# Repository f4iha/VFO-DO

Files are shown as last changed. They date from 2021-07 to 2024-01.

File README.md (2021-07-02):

# VFO-DO RF Generator

This VFO-DO is a HF generator covering from few kHz to 100MHz. This project provide to any beginner in electronic or radio the necessary elements to build a source of stable frequency (precise at the Herz level due to the steering by a GPS)... and it is very simple to build.

It is coming from the initial idea from Gene Marcus W3PM/GM4YRE and published in an [article](http://www.arrl.org/files/file/QEX_Next_Issue/2015/Jul-Aug_2015/Marcus.pdf) of QEX.
This repository is an evolution of the work done by F6ITU who provided a [KiCad project](https://github.com/F6ITU/VFO-DO/) for this VFO-DO.

This project can be used as field equipements, where it is unthinkable to move a served oscillator (fragile and expensive). This is mainly a simple approach to drive a little SDR or replace the VFO of a traditional radio device.

The cost of this is around 30 euros. However, please take in account the phase noise of this type of generator cannot compete with a traditional VFO-DO

## Specific features

During the integration, few changes were applied in the initial code of the author:
  * usage of a I2C Crystal Display, it is freeing multiple pin on the Arduino
  * add a button to disable the GPS at start

## Intellectual property and licence

The intellectual property and the publishing rights are owned respectively by the author and the publishing society mentioned.

Permission is granted to use, copy, modify, and distribute this firmware and documentation for non-commercial purposes.

## External links

More informations on the oscillator module based on SiLabs Si5351 : 
[https://learn.adafruit.com/adafruit-si5351-clock-generator-breakout?view=all](https://learn.adafruit.com/adafruit-si5351-clock-generator-breakout?view=all)

Another source for this module 
[https://www.sv1afn.com/si5351a.html](https://www.sv1afn.com/si5351a.html)
Careful : this last module is not "pin compatible" with the previous one

Origin firmware from the author [http://www.knology.net/~gmarcus/Si5351/Si5351_vfo_v5.ino.zip](http://www.knology.net/~gmarcus/Si5351/Si5351_vfo_v5.ino.zip)

A WSPR emitter-receiver designed by the author and using the VFO-DO
[http://www.knology.net/~gmarcus/Si5351/Si5351A_WSPR_XCVR.pdf](http://www.knology.net/~gmarcus/Si5351/Si5351A_WSPR_XCVR.pdf)

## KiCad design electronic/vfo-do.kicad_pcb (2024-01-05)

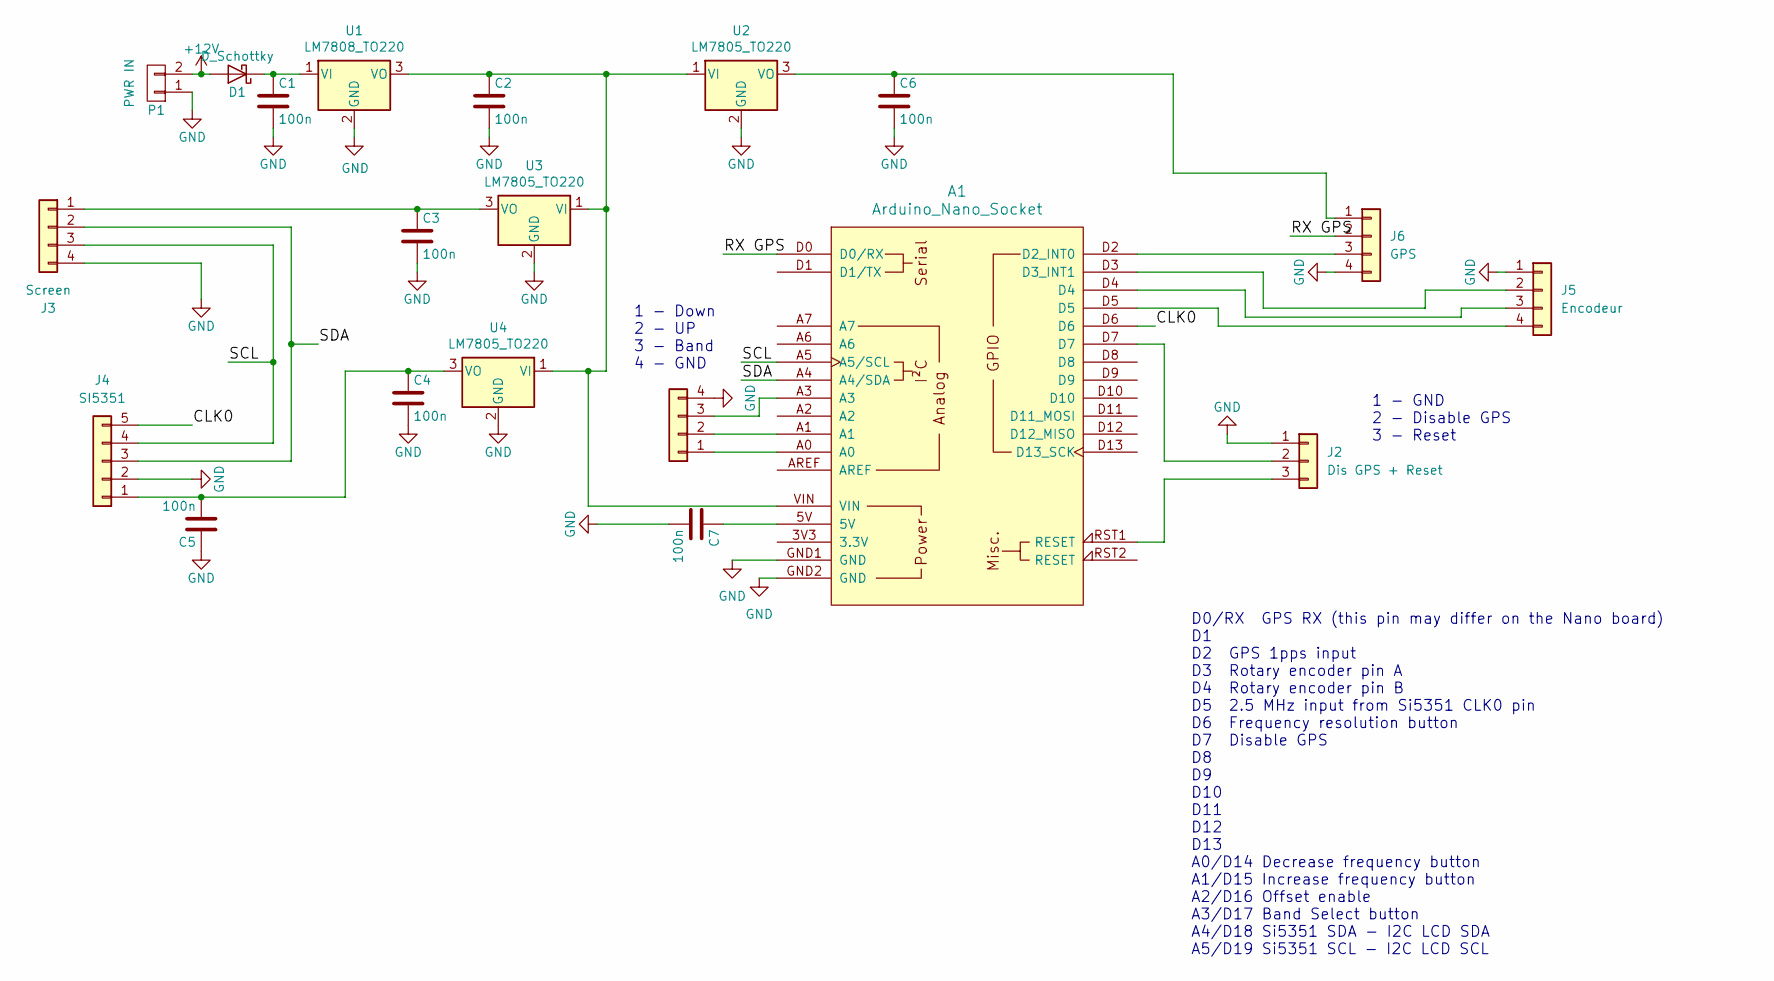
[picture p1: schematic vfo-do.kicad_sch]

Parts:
A1: Arduino_Nano_Socket
C1, C2, C3, C4, C5, C6, C7: 100n; C_Disc_D5.0mm_W2.5mm_P5.00mm
D1: D_Schottky; D_DO-41_SOD81_P7.62mm_Horizontal
J1: Commands; Molex_KK-254_AE-6410-04A_1x04_P2.54mm_Vertical
J2: Dis GPS + Reset; Molex_KK-254_AE-6410-03A_1x03_P2.54mm_Vertical
J3: Screen; Molex_KK-254_AE-6410-04A_1x04_P2.54mm_Vertical
J4: SI5351; Molex_KK-254_AE-6410-05A_1x05_P2.54mm_Vertical
J5: Encodeur; Molex_KK-254_AE-6410-04A_1x04_P2.54mm_Vertical
J6: GPS; Molex_KK-254_AE-6410-04A_1x04_P2.54mm_Vertical
P1: PWR IN; Molex_KK-254_AE-6410-02A_1x02_P2.54mm_Vertical
U1: LM7808_TO220; TO-220-3_Vertical
U2, U3, U4: LM7805_TO220; TO-220-3_Vertical

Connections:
+12V: D1.2 (A), P1.2
/CLK0: A1.D6, J4.5
/RX GPS: A1.D0 (D0/RX), J6.2
/SCL: A1.A5 (A5/SCL), J3.3, J4.4
/SDA: A1.A4 (A4/SDA), J3.2, J4.3
GND: A1.GND1 (GND), A1.GND2 (GND), C1.2, C2.2, C3.2, C4.2, C5.1, C6.2, C7.2, J1.4, J2.1, J3.4, J4.2, J5.1, J6.4, P1.1, U1.2 (GND), U2.2 (GND), U3.2 (GND), U4.2 (GND)
unnamed: A1.D2 (D2_INT0), J6.3
unnamed: A1.D3 (D3_INT1), J5.2
unnamed: A1.5V, C7.1
unnamed: C1.1, D1.1 (K), U1.1 (VI)
unnamed: A1.A0, J1.1
unnamed: A1.A1, J1.2
unnamed: A1.A3, J1.3
unnamed: A1.D7, J2.2
unnamed: A1.RST1 (RESET), J2.3
unnamed: C3.1, J3.1, U3.3 (VO)
unnamed: C4.1, C5.2, J4.1, U4.3 (VO)
unnamed: A1.D4, J5.3
unnamed: A1.D5, J5.4
unnamed: C6.1, J6.1, U2.3 (VO)
unnamed: A1.VIN, C2.1, U1.3 (VO), U2.1 (VI), U3.1 (VI), U4.1 (VI)

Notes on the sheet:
1 - Down 2 - UP 3 - Band 4 - GND
D0/RX GPS RX (this pin may differ on the Nano board) D1 D2 GPS 1pps input D3 Rotary encoder pin A D4 Rotary encoder pin B D5 2.5 MHz input from Si5351 CLK0 pin D6 Frequency resolution button D7 Disable GPS D8 D9 D10 D11 D12 D13 A0/D14 Decrease frequency button A1/D15 Increase frequency button A2/D1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
1 - GND 2 - Disable GPS 3 - Reset

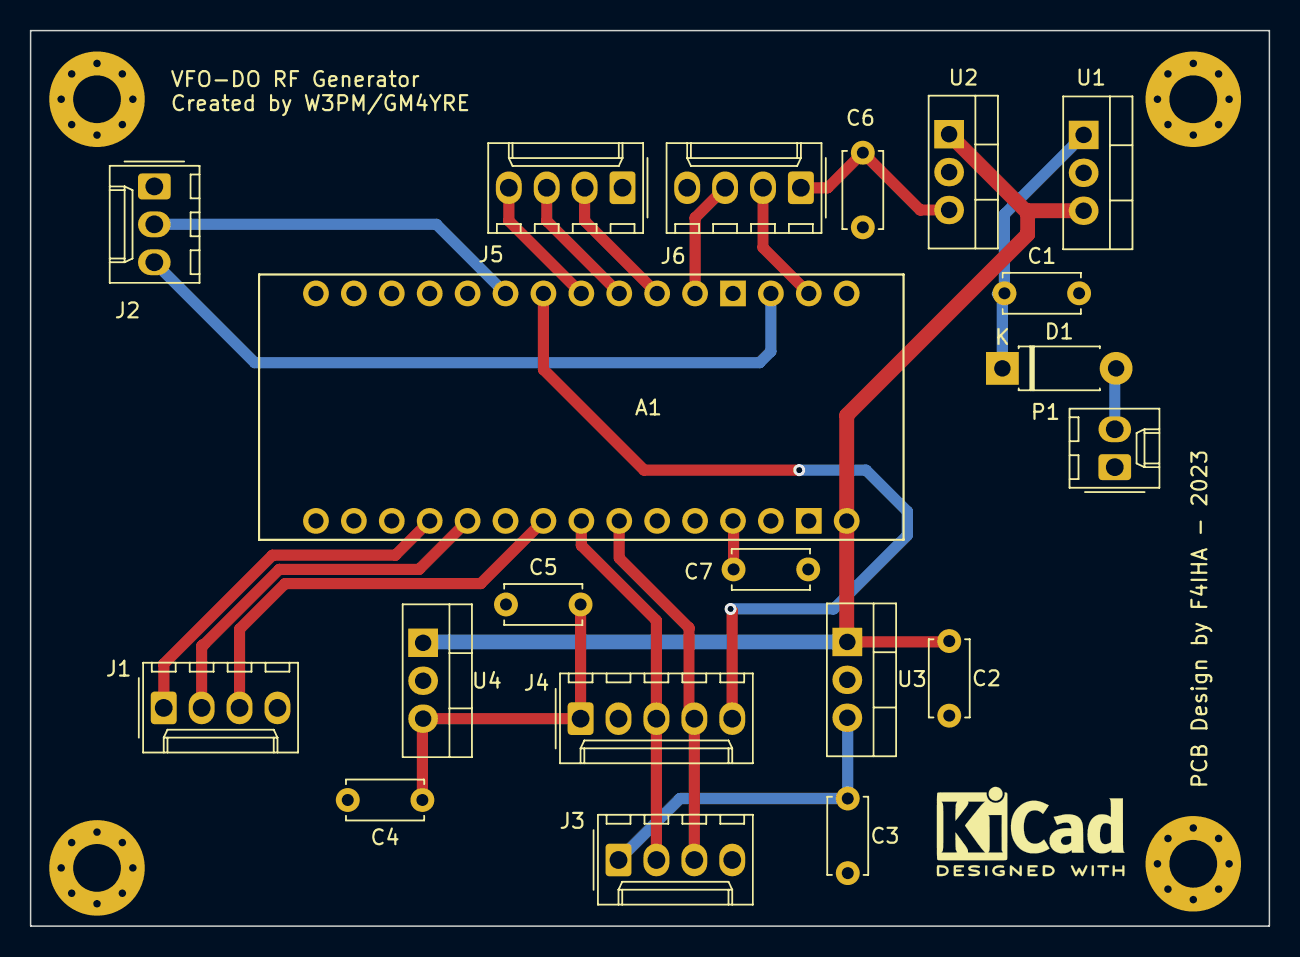
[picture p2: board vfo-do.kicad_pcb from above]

Board: 2 copper layers, 83.0 x 60.0 mm, 20 parts (0 on the bottom side), 21 nets.

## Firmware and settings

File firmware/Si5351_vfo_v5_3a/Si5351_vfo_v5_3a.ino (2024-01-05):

/*

 Arduino Controlled GPS Corrected Dual Output Si5351A VFO
 
 A VFO project that uses an Arduino Uno or Nano to control a SI5351A clock 
 generator breakout board. The VFO may be used in stand-alone mode or with 
 a GPS receiver to software calibrate the output frequency.
 
 Permission is granted to use, copy, modify, and distribute this software
 and documentation for non-commercial purposes.
 
 Copyright (C) 2014,  Gene Marcus W3PM GM4YRE
 
 16 December,2014
 
 v5     12 July, 2015    Corrected band select algorithm
 v5_1   13 July, 2015    Changed "KHz" to "kHZ" in the LCD frequency display
 v5_2   20 September,    2016 Modified debounce function to be compatible with 
                         Arduino IDE 1.6.11
 v5_3   28 January,2017  Modified coding to enhance 9600 operation. The modifcation
                         is courtesy of Jan, PE1CID.
 v5_3a  11 March, 2021   The variable "validGPSflag" can now equal 1 or 2 to proceed 
                         with normal operation                        
     
                                        
 
 Acknowledgements: 

 Special thanks to Jan, PE1CID for his effort to streamline the code and improve 
 operation at 9600 baud. Portions of the GPS receive code were influenced by 
 Igor Gonzalez Martin's Arduino tutorial. Thanks to N2END for finding compatibility 
 bug with Arduino 1.6.11 and testing revision v5_2.
 
 
 ------------------------------------------------------------------------
 Nano Digital Pin Allocation
 
 D0/RX  GPS RX (this pin may differ on the Nano board)
 D1  
 D2  GPS 1pps input 
 D3  Rotary encoder pin A
 D4  Rotary encoder pin B
 D5  Frequency resolution button
 D6  2.5 MHz input from Si5351 CLK0 pin
 D7  Disable GPS
 D8  
 D9  
 D10 
 D11
 D12
 D13 
 A0/D14 Decrease frequency button
 A1/D15 Increase frequency button
 A2/D16 Offset enable
 A3/D17 Band Select button               
 A4/D18 Si5351 SDA - I2C LCD SDA
 A5/D19 Si5351 SCL - I2C LCD SCL
  
 ----------------------------------------------------------------
 */

/*
_________________________________________________________________
 Band Select frequency format:
 
 Column 1 = CLK1 VFO start frequency in Hz
 Column 2 = CLK2 LO frequency in Hz
 Column 3 = LCD display arithmetic operation 
 0 = no change
 1 = Add CLK1 and CLK2
 2 = Subtract CLK1 from CLK2  
 
 Example: {5286500,8998500,1}, will result in
 LCD display: 14.285000 MHz
 CLK1 output: 5.286500 MHz 
 CLK2 output: 8.998500 MHz
 
 Enter any number of Band Select frequencies.  
 Use (0,0,0) as the last entry.    
 
 Restrict frequency entries to > 1 MHz and < 80 MHz
 
 ___________Enter Band Select frequencies below_____________________
 */
const unsigned long Freq_array [] [3] = {
  {  7030000,0,0      },            // CLK1=7.030 MHz, CLK2=0 MHz, Display=7,030.000 kHz
  {  1810000,0,0      },            
  {  3560000,0,0      },
  {  7040000,0,0      },
  { 10106000,0,0      },
  { 14060000,0,0      },
  { 18096000,0,0      },
  { 21060000,0,0      },
  { 24906000,0,0      },
  { 28060000,0,0      },
  { 50060000,0,0      },
  { 5286500,8998500,1 },      // CLK1:5.2865 MHz, CLK2:8.9985 MHz, Display:14,285.000 kHz
  { 5016500,9001500,2 },      // CLK1:5.0165 MHz, CLK2:9.0015 MHz, Display:3,985.00 kHz
  
  (0,0,0)
  };


//_________________________Enter offset frequency (Hz) below:__________________________________
int fOffset = -600;        // -600 Hz offset              


//_________________________GPS 1pps calibrate? (0 = NO, 1 = YES)_________________________________
int GPSflag = 1;


//___________________________Enter stand-alone calibration factor:______________________________
//    This entry is not required if GPS calibration is selected.
//  - Connect VFO to a frequency counter
//  - Set VFO to 25 MHz
//  - Annotate counter frequency in Hz
//  - Subtract 25 MHz from counter reading 
//  - Enter the difference in Hz (i.e. -245)
int CalFactor = 0;


// include the library code:
#include <LiquidCrystal_I2C.h>
#include <string.h>
#include <ctype.h>
#include <avr/interrupt.h>  
#include <avr/io.h>
#include <Wire.h>

// Set up MCU pins
#define ppsPin                   2 
#define encoderPinA              3 
#define encoderPinB              4
#define Resolution               5
#define GPSDisable               7
#define FreqDown                A0
#define FreqUp                  A1
#define Offset                  A2
#define BandSelect              A3

// Set LCD I2C address
#define LCD_addr              0x27

// Set sI5351A I2C address
#define Si5351A_addr          0x60 

// Define Si5351A register addresses
#define CLK_ENABLE_CONTROL       3
#define CLK0_CONTROL            16 
#define CLK1_CONTROL            17
#define CLK2_CONTROL            18
#define SYNTH_PLL_A             26
#define SYNTH_PLL_B             34
#define SYNTH_MS_0              42
#define SYNTH_MS_1              50
#define SYNTH_MS_2              58
#define PLL_RESET              177
#define XTAL_LOAD_CAP          183

// initialize the library with the size of the screen
LiquidCrystal_I2C lcd(LCD_addr, 20, 4);

// configure variables 
byte fStepcount,offsetFlag=0,band;
String resolution = "1 Hz  ";
char GPSlocator[7],StartCommand[7] = "$GPGGA",StartCommand2[7] = "$GPRMC",buffer[300] = "",EW,NS;
int IndiceCount=0,StartCount=0,counter=0,indices[13];
int Lat10,Lat1,Lon100,Lon10,Lon1,validGPSflag;
int dLon1,dLon2,dLat1,dLat2,dlon;
int byteGPS=-1,second=0,minute=0,hour=0;
unsigned int tcount=2,encoderA,encoderB,encoderC=1;
unsigned long time,fStep=1,XtalFreq=25000000;
unsigned long mult=0,Freq_1,Freq_2,debounce,DebounceDelay=500000;

static bool s_GpsOneSecTick = false; 

//******************************************************************
// Clock - interrupt routine used as master timekeeper
// Called every second by GPS 1PPS on MCU pin 2
//******************************************************************
void PPSinterrupt()
{
  s_GpsOneSecTick = true;                        // New second by GPS.

  tcount++;
  if (tcount == 4)                               // Start counting the 2.5 MHz signal from Si5351A CLK0
  {
    TCCR1B = 7;                                  //Clock on rising edge of pin 5
  }
  else if (tcount == 44)                              //The 40 second gate time elapsed - stop counting
  {     
    TCCR1B = 0;                                  //Turn off counter
    XtalFreq = mult * 0x10000 + TCNT1;           //Calculate correction factor
    TCNT1 = 0;                                   //Reset count to zero
    mult = 0;
    tcount = 0;                                  //Reset the seconds counter
  }
}

// Timer 1 overflow intrrupt vector.
ISR(TIMER1_OVF_vect) 
{
  mult++;                                          //Increment multiplier
  TIFR1 = (1<<TOV1);                               //Clear overlow flag 
}


void setup()
{

  pinMode(GPSDisable, INPUT);
  digitalWrite(GPSDisable, HIGH);           // internal pull-up enabled
  // if GPSDisable pressed at startup, GPS is not used
  if(digitalRead(GPSDisable) == LOW){
    GPSflag = 0;
  }
  Wire.begin(1);                  // join I2C bus (address = 1)
  si5351aStart();

  //Set up Timer1 as a frequency counter - input at pin 5
  TCCR1B = 0;                                    //Disable Timer5 during setup
  TCCR1A = 0;                                    //Reset
  TCNT1  = 0;                                    //Reset counter to zero
  TIFR1  = 1;                                    //Reset overflow
  TIMSK1 = 1;                                    //Turn on overflow flag

  // Inititalize GPS 1pps input
  pinMode(ppsPin, INPUT);

  // Set 1PPS pin 2 for external interrupt input
  attachInterrupt(digitalPinToInterrupt(ppsPin), PPSinterrupt, RISING);  

  // Add CalFactor to the Si5351 crystal frequency for non-GPS frequency updates
  if(GPSflag == 0)
  {
    XtalFreq += CalFactor;
    detachInterrupt(digitalPinToInterrupt(ppsPin)); // Disable the 1pps interrupt
  } 

  // Make XtalFreq compatable with GPS correction variable
  XtalFreq *= 4;

  // set up the LCD's number of columns and rows 
  lcd.begin(16,2); 

  // Set up rotary encoder
  pinMode(encoderPinA, INPUT);
  digitalWrite(encoderPinA, HIGH);         // internal pull-up enabled 
  pinMode(encoderPinB, INPUT);
  digitalWrite(encoderPinB, HIGH);         // internal pull-up enabled  

  // Set up push buttons
  pinMode(Resolution, INPUT);
  digitalWrite(Resolution, HIGH);         // internal pull-up enabled
  pinMode(BandSelect, INPUT);
  digitalWrite(BandSelect, HIGH);         // internal pull-up enabled
  pinMode(FreqDown, INPUT);
  digitalWrite(FreqDown, HIGH);           // internal pull-up enabled
  pinMode(Offset, INPUT);
  digitalWrite(Offset, HIGH);             // internal pull-up enabled
  pinMode(FreqUp, INPUT);
  digitalWrite(FreqUp, HIGH);             // internal pull-up enabled
  pinMode(FreqDown, INPUT);
  digitalWrite(FreqDown, HIGH);           // internal pull-up enabled

  Serial.begin(4800);                     // connect to the   port @ 4800 baud

  lcd.init();                          // initialize LCD
  lcd.backlight();
  lcd.setCursor(0,1);
  if (GPSflag == 1)
  {
    lcd.print("Waiting for GPS");         // This will continue to display until valid
  }                                       // GPS NMEA data is detected 
  else
  {
    lcd.print("Step:");                   // Frequency step resolution will display only 
    lcd.setCursor(6,1);                   // after valid GPS data is detected or if 
    lcd.print(resolution);                // stand-aloneoperation is selected.
  } 

  TCCR1B = 0;                             //Disable Timer5

  Freq_1 = Freq_array [0] [0];            // At start up load the first band in the the
  Freq_2 = Freq_array [0] [1];            // Freq_array variable.

  // Set CLK0 to 2.5 MHz
  si5351aSetFreq(SYNTH_MS_0,2500000); 

  if(Freq_2 == 0)
  {
    Si5351_write(CLK_ENABLE_CONTROL,0b00000100); // Turn OFF CLK2
  }
  else
  {
    Si5351_write(CLK_ENABLE_CONTROL,0b00000000); // Turn ON CLK2
    Freq_2 = Freq_array [band] [1];              // Load CLK2
    si5351aSetFreq(SYNTH_MS_2, Freq_2);          // Set CLK2 frequency
  }

  setfreq();                                     // Now display and set CLK1 frequency 

}



//******************************************************************
// Loop starts here:
// Loops consecutively to check MCU pins for activity
//******************************************************************
void loop()
{
  if (s_GpsOneSecTick)
  {
    s_GpsOneSecTick = false;
    if (validGPSflag == 1 | validGPSflag == 2)
    {
      updateAndDisplayUtcTime();

      if ((millis() > time) && (millis() <= time + 1000)) // Test to see if it is time to
      {                                                   // print grid square to the LCD
        lcd.setCursor(0,1);
        lcd.print(GPSlocator);
        lcd.print(" ");
      }
    }

    if (tcount == 1)                                  
    { 
      // Update the SI5351A after every GPS correction 
      si5351aSetFreq(SYNTH_MS_1, Freq_1);
      if (Freq_2 > 0)
      {
        si5351aSetFreq(SYNTH_MS_2, Freq_2);
      }
    }
  }
  
  if (GPSflag == 1 && validGPSflag == 0)
  {
    GPSprocess( ); //If GPS is selected, wait for valid NMEA data
  }
  else
  {

    // Rotary encoder algorithm begins here
    byte encoderA = digitalRead(encoderPinA); 
    byte encoderB = digitalRead(encoderPinB);
    if ((encoderA == HIGH) && (encoderC == LOW))
    {
      if (encoderB == LOW)
      {
        // Decrease frequency
        Freq_1 -= fStep; 
      }
      else
      {
        // Increase frequency
        Freq_1 += fStep;
      }
      setfreq();         //Update and display new frequency
      resDisplay();      //Update resolution display and set display timer
    }
    encoderC = encoderA;


    // The frequency step resolution selection begins here:
    if(digitalRead(Resolution) == LOW)
    {
      // This function is used in lieu of "delay" to prevent timer/interrupt conflicts
      for(debounce=0; debounce < DebounceDelay; debounce++){__asm__ __volatile__ ("nop");}; 
      fStepcount++;
      if(fStepcount>6)fStepcount=0;
      setResolution();     // Call the set resolution subroutine
    }

    // Band selection begins here:
    if(digitalRead(BandSelect) == LOW)
    {
      for(debounce=0; debounce < DebounceDelay; debounce++){__asm__ __volatile__ ("nop");};
      band=band+1;                        // Increment band selection
      if(Freq_array [band] [0]==0)band=0; // Check for end of frequency array
      if(Freq_array [band] [1] == 0)      // Is CLK2 = 0? 
      {
        Si5351_write(CLK_ENABLE_CONTROL,0b00000100); // Turn OFF CLK2
      }
      else
      {
        Si5351_write(CLK_ENABLE_CONTROL,0b00000000); // Turn ON CLK2
        Freq_2 = Freq_array [band] [1];              // Load CLK2 frequency
        si5351aSetFreq(SYNTH_MS_2, Freq_2);          // Set CLK2 frequency
      }
      Freq_1 = Freq_array [band] [0];                // Load CLK1 frequency 
      setfreq();                                     // Display and set CLK1 frequency
    }

    // Frequency offset algorithm begins here:  
    if(digitalRead(Offset) == LOW && offsetFlag == 0) // Check for offset pin A2 LOW
    { 
      offsetFlag = 1;                                 // Set flag
      Freq_1 += fOffset;                              // Add offset frequency
      lcd.setCursor(15,0);                            // Display a "*" on the LCD
      lcd.print("*");
      setfreq();                                      // Display and set CLK1 frequency + offset
    }

    if(digitalRead(Offset) == HIGH && offsetFlag == 1) // Check for offset pn A2 HIGH
    {
      offsetFlag = 0;                                  // Reset flag
      Freq_1 -= fOffset;                               // Subtract the offset frequency
      lcd.setCursor(15,0);                             // Clear the "*" on the LCD
      lcd.print(" ");
      setfreq();                                       // Display and set CLK1 frequency - offset
    }

    // Frequency Up/Down pushbutton algorithm begin here:
    if(digitalRead(FreqUp) == LOW)  // Check for frequency up pushbutton A1 LOW
    {
      for(debounce=0; debounce < DebounceDelay; debounce++){__asm__ __volatile__ ("nop");};
      // Increase frequency by the selected frequency step 
      Freq_1 += fStep;                                // Increase CLK1 by frequency step   
      setfreq();                                      // Set and display new frequency
      resDisplay();                                   // Call the resolution display subroutine
    }

    if(digitalRead(FreqDown) == LOW) // Check for frequency up pushbutton A1 LOW
    {
      for(debounce=0; debounce < DebounceDelay; debounce++){__asm__ __volatile__ ("nop");};
      // Decrease frequency by the selected frequency step and check for 1-80 MHz limits 
      Freq_1 -= fStep;                               // Decrease CLK1 by frequency step 
      setfreq();                                     // Set and display new frequency
      resDisplay();                                  // Call the resolution display subroutine
    }     
  }
}


//******************************************************************
// Add one second to the UTC time and update on the display
//******************************************************************
void updateAndDisplayUtcTime(void)
{
  second++;
  if (second == 60)                            //Set time using GPS NMEA data 
  {
    minute++ ;
    second = 0 ;
  }
  if (minute == 60) 
  {
    hour++;
    minute = 0 ;
  }
  if (hour == 24)
  {
    hour = 0 ;
  }
  //Output the UTC time to the LCD
  lcd.setCursor(8,1);
  if (hour < 10)
  {
    lcd.print ("0");
  }
  lcd.print (hour);
  lcd.print (":");
  if (minute < 10)
  {
    lcd.print ("0");
  }
  lcd.print (minute);
  lcd.print (":");
  if (second < 10)
  {
    lcd.print ("0");
  }
  lcd.print (second);
  lcd.print (" ");  
}

//******************************************************************
// Display and set the Si5351A frequency
//******************************************************************
void setfreq()
{
  unsigned long  Freq_temp = Freq_1; // Temporarily store Freq_1
  switch(Freq_array [band] [2])      // Get math function from frequency array
  {
  case 1:  // If math function is 1 then add Freq_1 and Freq_2 for display
    Freq_temp = Freq_1 + Freq_2;
    break;
  case 2:  // If math function is 2 then subtract Freq_1 from Freq_2 for display
    Freq_temp = Freq_2 - Freq_1;
    break;
  }
  char buf[10];

  // Print frequency to the LCD
  lcd.setCursor(0,0);

  ltoa(Freq_temp,buf,10);

  if (Freq_temp < 1000000)
  {
    lcd.print(buf[0]);
    lcd.print(buf[1]);
    lcd.print(buf[2]);
    lcd.print('.');
    lcd.print(buf[3]);
    lcd.print(buf[4]);
    lcd.print(buf[5]);
    lcd.print(" kHz     ");         
  }

  if (Freq_temp >= 1000000 && Freq_temp < 10000000)
  {
    lcd.print(buf[0]);
    lcd.print(',');
    lcd.print(buf[1]);
    lcd.print(buf[2]);
    lcd.print(buf[3]);
    lcd.print('.');
    lcd.print(buf[4]);
    lcd.print(buf[5]);
    lcd.print(buf[6]);
    lcd.print(" kHz   ");
  }

  if (Freq_temp >= 10000000 && Freq_temp < 100000000)
  {
    lcd.print(buf[0]);
    lcd.print(buf[1]);
    lcd.print(',');
    lcd.print(buf[2]);
    lcd.print(buf[3]);
    lcd.print(buf[4]);
    lcd.print('.');
    lcd.print(buf[5]);
    lcd.print(buf[6]);
    lcd.print(buf[7]);
    lcd.print(" kHz  ");
  }

  if (Freq_temp >= 100000000)
  {
    lcd.print(buf[0]);
    lcd.print(buf[1]);
    lcd.print(buf[2]);
    lcd.print(',');
    lcd.print(buf[3]);
    lcd.print(buf[4]);
    lcd.print(buf[5]);
    lcd.print('.');
    lcd.print(buf[6]);
    lcd.print(buf[7]);
    lcd.print(buf[8]);
    lcd.print(" kHz ");
  }  
  
  si5351aSetFreq(SYNTH_MS_1, Freq_1); // Set CLK1 frequency
}


//******************************************************************
// Set the frequency step resolution
//******************************************************************
void setResolution()
{
  switch(fStepcount)
  {
  case 0:
    fStep=1;
    resolution = "1 Hz  ";
    break;
  case 1:
    fStep=10;
    resolution = "10 Hz  ";
    break;
  case 2:
    fStep=100;
    resolution = "100 Hz ";
    break;
  case 3:
    fStep=1000;
    resolution = "1 kHz  ";
    break;
  case 4:
    fStep=10000;
    resolution = "10 kHz ";
    break;
  case 5:
    fStep=100000;
    resolution = "100 kHz";
    break;
  case 6:
    fStep=1000000;
    resolution = "1 MHz  ";
    break;
  }
  resDisplay();
}

//******************************************************************
// Display the frequency step resolution and 
// set a 10 second display timer
//******************************************************************
void resDisplay()
{
  if (GPSflag == 0) lcd.setCursor(6,1);
  else lcd.setCursor(0,1);
  lcd.print(resolution);
  time = millis()+10000;
}


//******************************************************************
// Calculate the 6 digit Maidenhead Grid Square location
//******************************************************************
void calcGridSquare()
{
  unsigned long latitude, longitude;
  float temp3,tempLat,tempLong;
  longitude = Lon100*100000000L+Lon10*10000000L+Lon1*1000000L+dLon1*100000L+dLon2*10000L;
  latitude = Lat10*10000000L+Lat1*1000000L+dLat1*100000L+dLat2*10000L;
  tempLong=longitude;
  tempLong=1000000*int(tempLong/1000000)+ ((tempLong-1000000*int(tempLong/1000000))/0.6); 
  if (EW == 'E')tempLong=(tempLong)+180000000;
  if (EW == 'W')tempLong=180000000-(tempLong);
  tempLat=latitude;
  tempLat=1000000*int(tempLat/1000000)+((tempLat-1000000*int(tempLat/1000000))/0.6);   
  if (NS=='N')tempLat=tempLat+90000000;
  if (NS=='S')tempLat=90000000-tempLat;
  GPSlocator[0]=(65+int(tempLong/20000000));
  GPSlocator[1]=(65+int(tempLat/10000000));
  temp3=tempLong-(20000000*int(tempLong/20000000)); 
  GPSlocator[2]=(48+int(temp3*10/20/1000000)); 
  temp3=tempLat-(10000000*int(tempLat/10000000));  
  GPSlocator[3]=(48+int(temp3/1000000)); 
  temp3=(tempLong/2000000)-(int(tempLong/2000000));
  GPSlocator[4]=(97+int(temp3*24));
  temp3=(tempLat/1000000)-(int(tempLat/1000000));
  GPSlocator[5]=(97+int(temp3*24));
}
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

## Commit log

2021-06-25 Commit initial
    [vfo-do.sch]
2021-06-25 Switching screen to I2C support
2021-06-25 Fix compilation error and add button to disable GPS at start
    [Si5351_vfo_v5_3a.ino]
2021-09-13 Add GPS switchoff button
    [vfo-do.sch]
2021-12-27 Migrate Kicad5 to Kicad6
    [vfo-do.kicad_sch, vfo-do.sch]
2021-12-27 Migration Kicad5 to Kicad6
2024-01-05 electronics changes for PCB
    [vfo-do.kicad_pcb, vfo-do.kicad_sch]
2024-01-05 Firmware pin adjustments for PCB
2024-01-05 Gerber files
    [vfo-do-B_Cu.gbl, vfo-do-B_Mask.gbs, vfo-do-B_Paste.gbp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]
2024-01-05 Rename gerber to pcb folder
    [vfo-do-B_Cu.gbl, vfo-do-B_Mask.gbs, vfo-do-B_Paste.gbp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]
